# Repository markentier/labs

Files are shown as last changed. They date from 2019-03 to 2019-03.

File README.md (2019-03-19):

# markentier.tech labs

**Collection of electronics/maker projects.**

* [fivebeans Coffee Notification Button](./fivebeans-cnb/README.md)

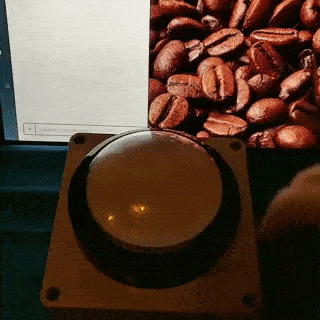
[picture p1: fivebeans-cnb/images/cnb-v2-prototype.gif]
  

## Notes

Most code projects will use [platformIO](https://platformio.org/) setup for source code.
It shouldn't be too difficult to use them with an [Arduino IDE](https://www.arduino.cc/en/Main/Software) again if needed.
PCB designs are done with [KiCAD](http://kicad-pcb.org/).

I won't describe each project in detail, the READMEs will be pretty barebone sometimes.
Source code, schematics, layout, and Gerber files are provided as-is.

In general this repo serves mostly as a public backup and share for the interested folks.

### License and Open Source information

If not stated otherwise all files authored by me are dual-licensed under [MIT license](./LICENSE-MIT) and [Creative Commons CC-BY-SA 4.0](./LICENSE-CC); third party symbols and footprints might fall under different licenses.
KiCAD data usually uses a [Creative Commons CC-BY-SA 4.0](https://creativecommons.org/licenses/by-sa/4.0/legalcode), also read <http://kicad-pcb.org/libraries/license/> for details and exceptions/waiver.
Similar rules apply to the [DigiKey collection](https://github.com/digikey/digikey-kicad-library/).
Thus I try to use KiCAD/DigiKey libraries as much as possible.

The hardware/electronics designs are published in accordance with the [statement of principles and definition of the Open Source Hardware Association](https://www.oshwa.org/definition/).

_If you believe I violate anyone's rights or wrongly relicense their work, please contact me (open an issue) and let's find a suitable solution for all involved parties._

I use the MIT license out of habit and since it's short and unrestricted (the ISC or 0BSD might be suitable candidates as well). The CC license is used, because it seems to be widely adopted in the Open Source Hardware community, so I want to be open in that direction, too. Since I find it too cumbersome to individually declare, both source code and any other media (schematics, layouts, ...) fall under the same dual licensing, even though Creative Commons is usually not used for source code. As you might find it unsuitable (and CC itself recommends not doing it anyway), consider using the source code under the MIT license instead. No, no third option will be introduced anytime soon.

### OSHW Statement of Principles 1.0

> Open source hardware is hardware whose design is made publicly available so that anyone can study, modify, distribute, make, and sell the design or hardware based on that design. The hardware's source, the design from which it is made, is available in the preferred format for making modifications to it. Ideally, open source hardware uses readily-available components and materials, standard processes, open infrastructure, unrestricted content, and open-source design tools to maximize the ability of individuals to make and use hardware. Open source hardware gives people the freedom to control their technology while sharing knowledge and encouraging commerce through the open exchange of designs.

— <https://www.oshwa.org/definition/>

### Quote from "OSI Mission"

> Open source enables a development method for software that harnesses the power of distributed peer review and transparency of process. The promise of open source is higher quality, better reliability, greater flexibility, lower cost, and an end to predatory vendor lock-in.

— <https://opensource.org/about>

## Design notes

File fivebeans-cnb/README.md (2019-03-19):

# fivebeans Coffee Notification Button

<p align="center">
  
</p>

An ESP8285 (or ESP8266) which sends a Slack message into a channel once a big button is pressed.

Show status of progress with a 24 pixel WS2812B LED ring (also known as Neopixel).

After job is done, the ESP will be turned off (so it needs an LDO with ENABLE/SHUTDOWN pin).

It's basically an overcomplicated "dash button" with fancy lights in a button and housed in a very huge case.
Funnily enough I shrunk the PCB way more than needed for the case, but I liked this challenge and wanted to get familiar with SMD soldering anyway.

## Future ideas

* use an SMD version of the ESP8266 (like ESP-12F)
* use an ESP-32 and utilize the 2 cores (main task doing all the communication + secondary task keeping the lights running concurrently)
* use an SMD ATtiny## with the ESP82## for concurrently driving the LEDs?
* _Do you have an interesting idea? Open an issue and tell me!_

The SMD ESPs would make the board bigger again, because I need to mount them somehow to the PCB, but that's okay probably. Certainly I don't want to use th bare chips and deal with antenna magic, I leave [this journey](https://www.youtube.com/watch?v=am68wkDK9UE) to the [Unexpected Maker](https://github.com/unexpectedmaker).

## Images and short videos

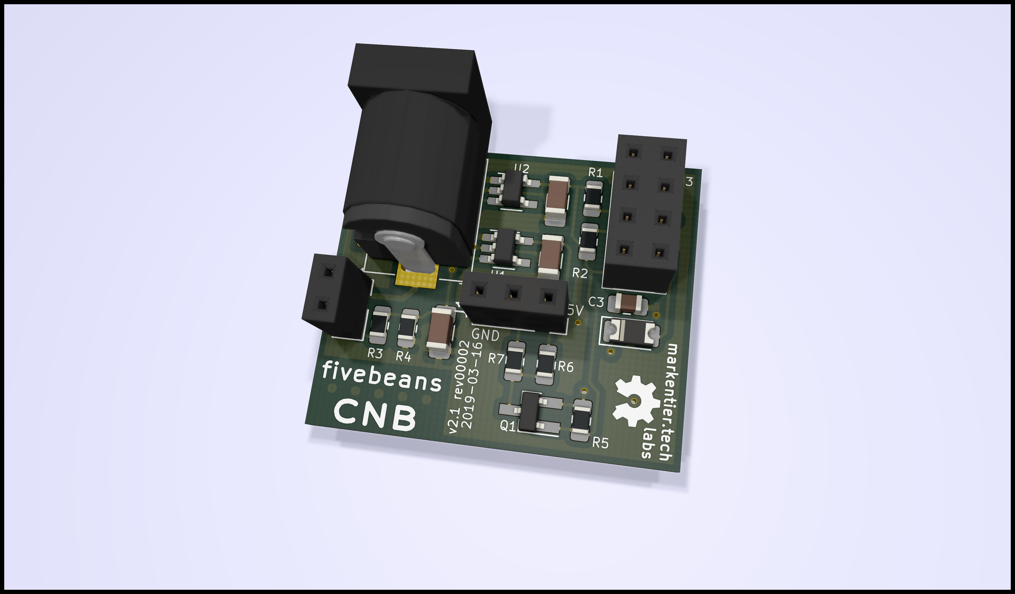
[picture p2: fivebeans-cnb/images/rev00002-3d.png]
PCB 3D rendering for v2.1 rev00002

<small>`PCB 3D rendering for v2.1 rev1`</small>

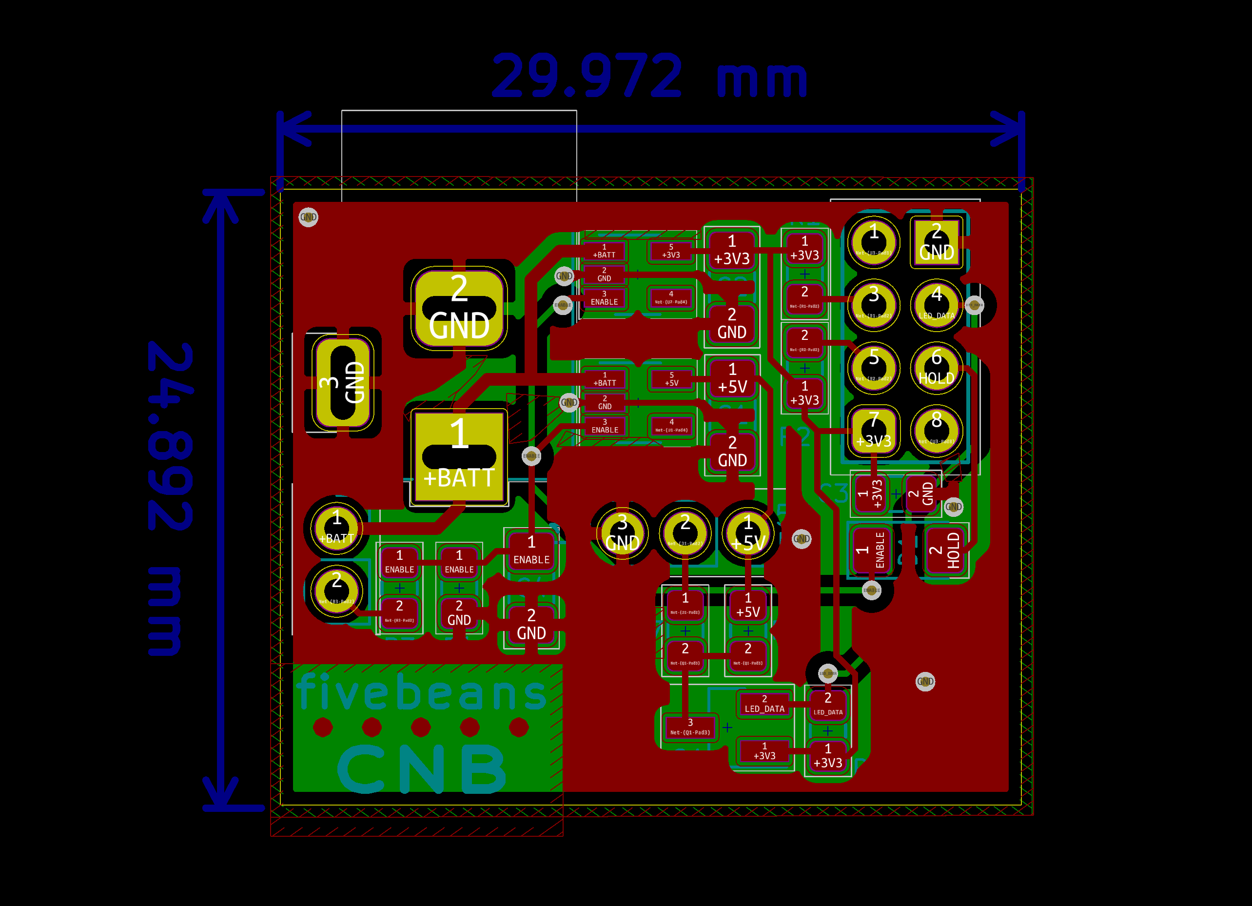
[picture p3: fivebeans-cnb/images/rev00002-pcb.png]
PCB schematic rendering for v2.1 rev00002

<small>`PCB schematic rendering for v2.1 rev1`</small>

* Early prototype (Jan 2018)
  * 🎥 https://www.instagram.com/p/BefYRcdHyhK/
  * 📸 https://www.instagram.com/p/Begb8exn_ND/
* Next version on a breadboard (Feb 2019)
  * 🎥 https://www.instagram.com/p/Btrnet4omIN/
  * 📸 https://www.instagram.com/p/BtrqztWIw97/
* First self-designed PCB prototype (Feb 2019)
  * 📸 https://www.instagram.com/p/Bt_dyOYBbQA/
  * 🎥/📸 https://www.instagram.com/p/BuC8_eaBRkF/
* v2.1 rev00001 (March 2019)
  * 📸 https://www.instagram.com/p/BvDQuSpnnQZ/
  * 📸 https://www.instagram.com/p/BvFaA8wnASO/
* v2.1 rev00002 (March 2019)
  * _coming soon_

## Components

| Component  | Amount  | Notes  |
|---|---|---|
| PCB  | 1  | see kicad project  |
| ESP8285  | 1  | an ESP8266 should still work  |
| WS2812B 24 pixel ring  | 1  | RGB LEDs; so called Neopixel ring  |
| 18650 cell  | 2  | 2000mAh or better  |
| battery holder (for 2 cells)  | 1  | with a DC Jack connector  |
| wires (Dupont)  | 5  | for button and LED ring  |
| (components for PCB)  | many  | _tbd (check kicad schematic)_ |

## Frameworks

Per default the [ESP8266 Arduino framework](https://github.com/esp8266/Arduino) is used and code should be usable in their IDE.

There are other frameworks usable with ESP8266/ESP8285, but haven't done any testing yet.
Especially for JSON support one should look for a generic C/C++ library suitable for embedded devices.

### nonOS SDK

Framework: https://github.com/espressif/ESP8266_NONOS_SDK

Compatible platformio libraries: https://platformio.org/lib/search?query=framework:%22esp8266-nonos-sdk%22

### RTOS SDK

Framework: https://github.com/espressif/ESP8266_RTOS_SDK

Compatible platformio libraries: https://platformio.org/lib/search?query=framework:%22esp8266-rtos-sdk%22

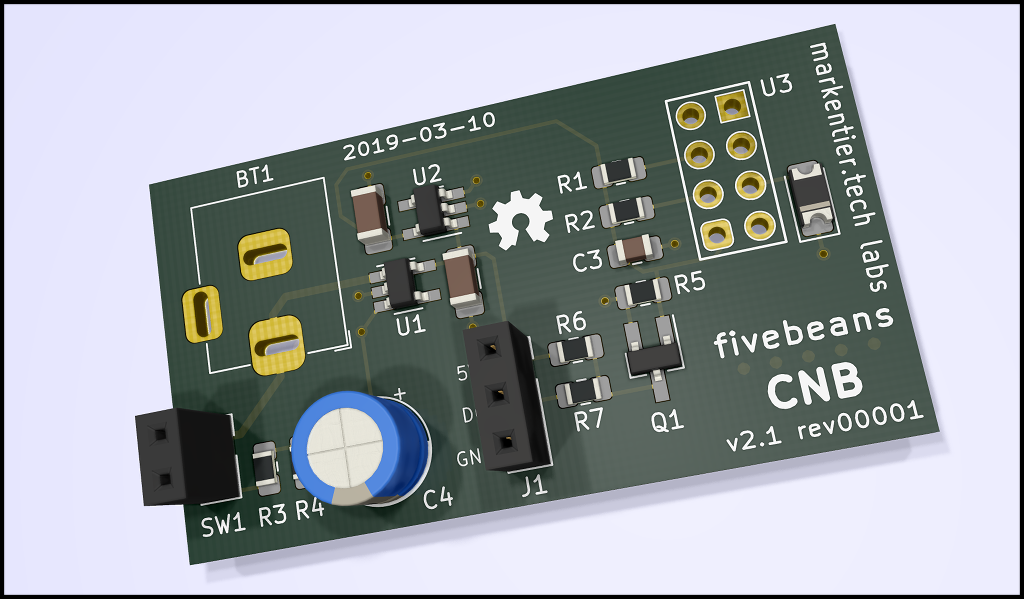
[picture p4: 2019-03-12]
fivebeans-cnb/images/cnb-render-v2.1-rev00001.png

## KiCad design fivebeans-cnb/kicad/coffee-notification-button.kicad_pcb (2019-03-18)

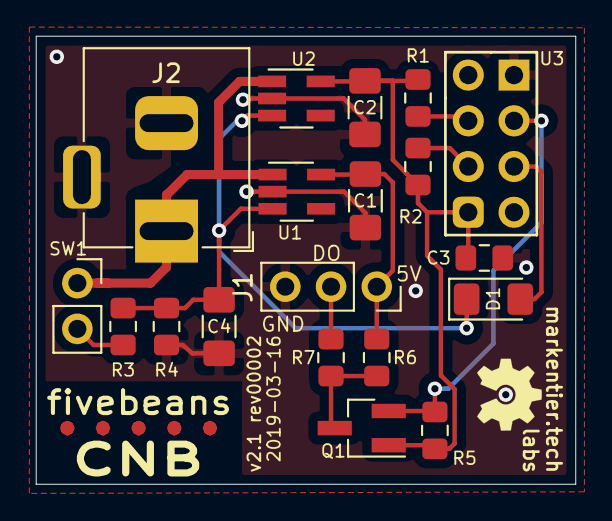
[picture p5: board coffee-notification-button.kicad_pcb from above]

Board: 2 copper layers, 30.0 x 24.9 mm, 19 parts (0 on the bottom side), 12 nets.

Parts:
C1, C2: 2.2uF; C_1206_3216Metric_Pad1.42x1.75mm_HandSolder
C3: 1uF; C_0805_2012Metric_Pad1.15x1.40mm_HandSolder
C4: 10uF; C_1206_3216Metric_Pad1.42x1.75mm_HandSolder
D1: 1N4001; D_1206_3216Metric_Pad1.42x1.75mm_HandSolder
J1: Conn_WS2812B; PinSocket_1x03_P2.54mm_Vertical
J2: Barrel_Jack_Switch; BarrelJack_Horizontal_short-silk
Q1: FDV301N; SOT-23_Handsoldering
R1, R2, R5, R6: 10k; R_0805_2012Metric_Pad1.15x1.40mm_HandSolder
R3: 220; R_0805_2012Metric_Pad1.15x1.40mm_HandSolder
R4: 22k; R_0805_2012Metric_Pad1.15x1.40mm_HandSolder
R7: 330; R_0805_2012Metric_Pad1.15x1.40mm_HandSolder
SW1: SW_DIP_x01; PinSocket_1x02_P2.54mm_Vertical
U1: MIC5219-5.0YM5; SOT-23-5_HandSoldering
U2: MIC5219-3.3YM5; SOT-23-5_HandSoldering
U3: ESP-01 (8266 or 8285); ESP-01_no_silk_outline

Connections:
+3V3: C2.1, C3.1, Q1.1, R1.1, R2.1, R5.1, U2.5, U3.7
+5V: C1.1, J1.1, R6.1, U1.5
+BATT: J2.1, SW1.1, U1.1, U2.1
/ENABLE: C4.1, D1.1, R3.1, R4.1, U1.3, U2.3
/HOLD: D1.2, U3.6
/LED_DATA: Q1.2, R5.2, U3.4
GND: C1.2, C2.2, C3.2, C4.2, J1.3, J2.2, J2.3, R4.2, U1.2, U2.2, U3.2
unnamed: J1.2, R7.1
unnamed: Q1.3, R6.2, R7.2
unnamed: R1.2, U3.3
unnamed: R2.2, U3.5
unnamed: R3.2, SW1.2

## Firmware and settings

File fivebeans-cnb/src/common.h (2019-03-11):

extern "C" {
#include "user_interface.h"
}
#include <ESP8266WiFi.h>
#include <ESP8266WiFiMulti.h>
#include <WiFiClientSecure.h>
#include <ArduinoJson.h>
#include <Adafruit_NeoPixel.h>
#include <time.h>

#include "wifi_settings.h"
#include "slack_settings.h"

// #define CDATE __DATE__
// #define CTIME __TIME__
// #define CTS __TIMESTAMP__

#ifdef DEBUG
#define DEBUG_SERIAL_INIT(baud) Serial.begin(baud)
#define DEBUG_PRINT(data) Serial.print(data)
#define DEBUG_PRINTLN(data) Serial.println(data)
#else
#define DEBUG_SERIAL_INIT(...) (void)0
#define DEBUG_PRINT(...) (void)0
#define DEBUG_PRINTLN(...) (void)0
#endif

#define HOLD_PIN 0
#define NEOPIXEL_PIN 2
#define NEOPIXEL_LED_COUNT 24

#define DEFAULT_LOOPS 3
#define DEFAULT_DELAY 125

#define SHORT_LOOPS 9
#define SHORT_DELAY 33
#define BLIP_LOOPS 3

void initialize_it();
void initialize_pins();

void run_tasks();

void connect_wifi();
void disable_wifi();
void setClock();

void send_message_with_retry();
bool send_message();

void colorWipe(uint32_t c, uint8_t wait);
void dotted(uint32_t c, uint8_t wait);
uint32_t Wheel(byte WheelPos);

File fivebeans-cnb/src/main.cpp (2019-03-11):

#include "common.h"

ESP8266WiFiMulti wifiMulti;
BearSSL::WiFiClientSecure client;

Adafruit_NeoPixel strip = Adafruit_NeoPixel(NEOPIXEL_LED_COUNT, NEOPIXEL_PIN, NEO_GRB + NEO_KHZ800);

void setup() {
  initialize_it();
  run_tasks();

  for(int b = 100; b > -1; b--) {
    strip.setBrightness(b);
    strip.show();
    delay(12);
  }
  delay(100);
  DEBUG_PRINTLN(F("(turn off)"));
  digitalWrite(HOLD_PIN, LOW);
  delay(1000);
}

void loop() {}

//------------------------------------------------------------------------------

void initialize_it() {
  DEBUG_SERIAL_INIT(115200);
  initialize_pins();
  strip.begin();
  strip.setBrightness(0);
  strip.show();
  strip.setBrightness(100);
  DEBUG_PRINTLN(F("(initialized)"));
}

void initialize_pins() {
  pinMode(HOLD_PIN, OUTPUT);
  digitalWrite(HOLD_PIN, HIGH);
}

//------------------------------------------------------------------------------

void run_tasks() {
  colorWipe(strip.Color(0,0,16), 50);
  colorWipe(strip.Color(0,0,0), 12);

  connect_wifi();

  colorWipe(strip.Color(32,0,32), 25);
  colorWipe(strip.Color(0,0,0), 12);

  setClock();

  colorWipe(strip.Color(64,64,0), 25);
  colorWipe(strip.Color(0,0,0), 6);

  send_message_with_retry();

  disable_wifi();
}

//------------------------------------------------------------------------------

void connect_wifi() {
  WiFi.mode(WIFI_STA);
  wifiMulti.addAP(WIFI_SSID, WIFI_PW);
  while(wifiMulti.run() != WL_CONNECTED) {
    colorWipe(strip.Color(0,0,64), 12);
    colorWipe(strip.Color(0,0,0), 12);
  }

  DEBUG_PRINTLN(F("WiFi connected"));
  DEBUG_PRINTLN(F("IP address: "));
  DEBUG_PRINTLN(WiFi.localIP());

  client.setFingerprint(SLACK_SSL_FINGERPRINT);
}

void disable_wifi() {
  WiFi.disconnect();
  WiFi.mode(WIFI_OFF);
}

void setClock() {
  configTime(0, 0, "pool.ntp.org", "ptbtime1.ptb.de", "zeit.fu-berlin.de");

  DEBUG_PRINT(F("Waiting for NTP time sync: "));
  time_t now = time(nullptr);
  while (now < 8 * 3600 * 2) {
    delay(500);
    DEBUG_PRINT(F("."));
    now = time(nullptr);
  }
  DEBUG_PRINTLN("");
  struct tm timeinfo;
  gmtime_r(&now, &timeinfo);
  DEBUG_PRINT(F("Current time: "));
  DEBUG_PRINT(asctime(&timeinfo));
}

//------------------------------------------------------------------------------

void send_message_with_retry() {
  bool success = false;

  for(int r = 0; r < 5; r++) {
    DEBUG_PRINT(F("Attempt #")); DEBUG_PRINTLN(r + 1);
    success = send_message();
    if(success) break;
    colorWipe(strip.Color(64,24,0), 50);
    colorWipe(strip.Color(0,0,0), 50);
    delay(250);
  }

  if(success) {
    DEBUG_PRINTLN(F("Message sent."));
    colorWipe(strip.Color(0,64,0), 100);
    //colorWipe(strip.Color(0,0,0), 100);
  } else {
    DEBUG_PRINTLN(F("... message sending failed."));
    colorWipe(strip.Color(64,0,0), 100);
    //colorWipe(strip.Color(0,0,0), 50);
  }
}

bool send_message() {
/*
{
    "attachments": [
        {
            "fallback": "Check the kitchen, there might be fresh coffee! :chemex: :coffee: :praisethesun:",
            "color": "#331100",
            "title": "Check the kitchen, there might be fresh coffee! :coffee:",
            "footer": "Coffee Notification Button by Christoph",
            "ts": 150123123
        }
    ]
}
*/

  DynamicJsonBuffer jsonBuffer;
  DynamicJsonBuffer attachmentBuffer;
  JsonObject& json = jsonBuffer.createObject();
  JsonArray& attachments = json.createNestedArray("attachments");

  JsonObject& attachment = attachmentBuffer.createObject();
  attachment["fallback"] = String("Check the kitchen, there might be fresh coffee! :chemex: :coffee: :praisethesun:");
  attachment["color"] = String("#552200");
  attachment["title"] = String("Check the kitchen, there might be fresh coffee! :chemex:");
  attachment["text"] = String("Location: BER-2-SW-Kitchen-RR");
  attachment["footer"] = String("Coffee Notification Button by Christoph");

  time_t now = time(nullptr);
  attachment["ts"] = now;

  attachments.add(attachment);

  DEBUG_PRINTLN(F("Connecting to host ..."));
  if (!client.connect(F(SLACK_WH_HOST), 443)) {
    DEBUG_PRINTLN(F("Connection failed"));

    client.stop();
    return false;
  }
  DEBUG_PRINTLN(F("Connected to host"));

  String message;
  json.printTo(message);

  String request = "";
    request += "POST " + String(F(SLACK_WH_PATH)) + " HTTP/1.1\r\n";
    request += "Host: " + String(F(SLACK_WH_HOST)) + "\r\n";
    request += "User-Agent: esp8266/arduino/slack-test\r\n";
    request += "Accept: application/json\r\n";
    request += "Content-Type: application/json\r\n";
    request += "Connection: close\r\n";
    request += "Content-Length: "+ String(message.length()) + "\r\n";
    request += "\r\n";
    request += message;

  DEBUG_PRINTLN(request);
  client.print(request);

  long timeout = millis() + 5000;
  while(!client.available()) {
    dotted(strip.Color(32,16,0), 12);
    dotted(strip.Color(0,0,0), 6);
    if (millis() > timeout) {
      DEBUG_PRINTLN(F("Request timed out"));
      client.stop();
      return false;
    }
  }

  client.stop();
  return true;
}


//--- adafruit neopixel examples

// Fill the dots one after the other with a color
void colorWipe(uint32_t c, uint8_t wait) {
  for(uint16_t i=0; i<strip.numPixels(); i++) {
    strip.setPixelColor(i, c);
    strip.show();
    delay(wait);
  }
}

void dotted(uint32_t c, uint8_t wait) {
  for(uint16_t i=0; i<strip.numPixels(); i++) {
    if(i % 3 != 0) continue;
    strip.setPixelColor(i, c);
    strip.show();
    delay(wait);
  }
}

//void rainbow(uint8_t wait) {
//  uint16_t i, j;
//
//  for(j=0; j<256; j++) {
//    for(i=0; i<strip.numPixels(); i++) {
//      strip.setPixelColor(i, Wheel((i+j) & 255));
//    }
//    strip.show();
//    delay(wait);
//  }
//}

// Input a value 0 to 255 to get a color value.
// The colours are a transition r - g - b - back to r.
uint32_t Wheel(byte WheelPos) {
  WheelPos = 255 - WheelPos;
  if(WheelPos < 85) {
    return strip.Color(255 - WheelPos * 3, 0, WheelPos * 3);
  }
  if(WheelPos < 170) {
    WheelPos -= 85;
    return strip.Color(0, WheelPos * 3, 255 - WheelPos * 3);
  }
  WheelPos -= 170;
  return strip.Color(WheelPos * 3, 255 - WheelPos * 3, 0);
}

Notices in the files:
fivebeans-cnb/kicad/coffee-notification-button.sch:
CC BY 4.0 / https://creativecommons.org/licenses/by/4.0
